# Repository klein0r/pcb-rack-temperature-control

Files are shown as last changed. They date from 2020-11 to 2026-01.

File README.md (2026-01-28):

# Rack Temperature Control

[Gerber-Files](https://github.com/klein0r/pcb-rack-temperature-control/releases)

## Preview

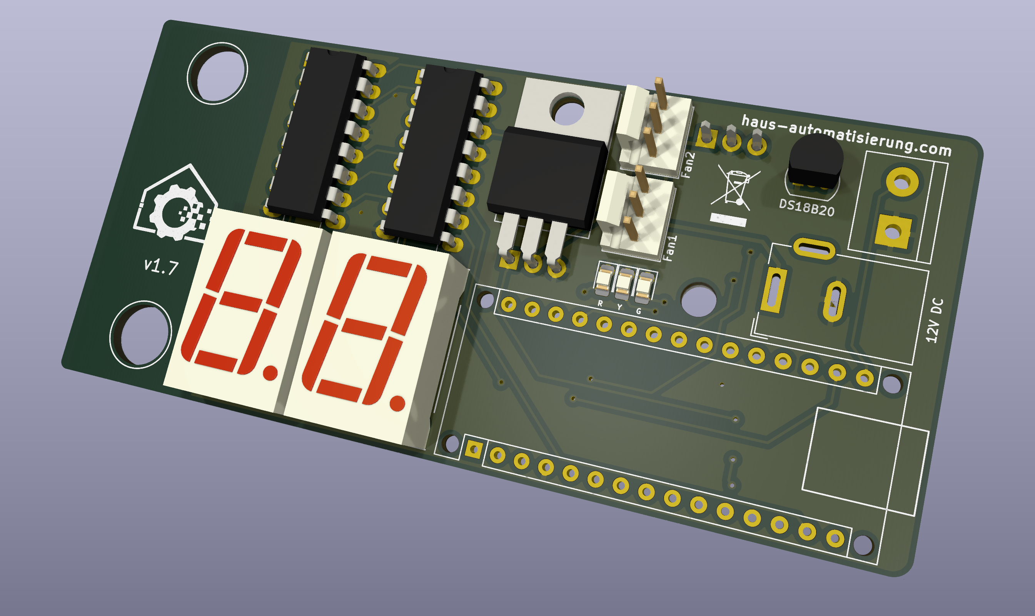
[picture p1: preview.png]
PCB Preview


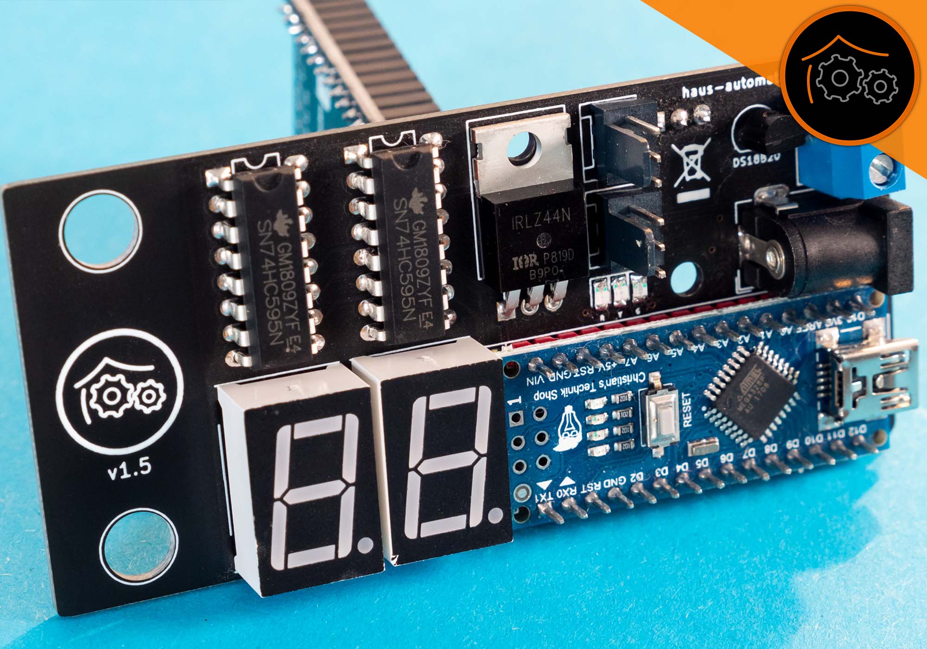
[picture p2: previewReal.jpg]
PCB Photo


## License

The MIT License (MIT)

Copyright (c) 2026 Matthias Kleine <info@haus-automatisierung.com>

Permission is hereby granted, free of charge, to any person obtaining a copy
of this software and associated documentation files (the "Software"), to deal
in the Software without restriction, including without limitation the rights
to use, copy, modify, merge, publish, distribute, sublicense, and/or sell
copies of the Software, and to permit persons to whom the Software is
furnished to do so, subject to the following conditions:

The above copyright notice and this permission notice shall be included in
all copies or substantial portions of the Software.

THE SOFTWARE IS PROVIDED "AS IS", WITHOUT WARRANTY OF ANY KIND, EXPRESS OR
IMPLIED, INCLUDING BUT NOT LIMITED TO THE WARRANTIES OF MERCHANTABILITY,
FITNESS FOR A PARTICULAR PURPOSE AND NONINFRINGEMENT. IN NO EVENT SHALL THE
AUTHORS OR COPYRIGHT HOLDERS BE LIABLE FOR ANY CLAIM, DAMAGES OR OTHER
LIABILITY, WHETHER IN AN ACTION OF CONTRACT, TORT OR OTHERWISE, ARISING FROM,
OUT OF OR IN CONNECTION WITH THE SOFTWARE OR THE USE OR OTHER DEALINGS IN
THE SOFTWARE.

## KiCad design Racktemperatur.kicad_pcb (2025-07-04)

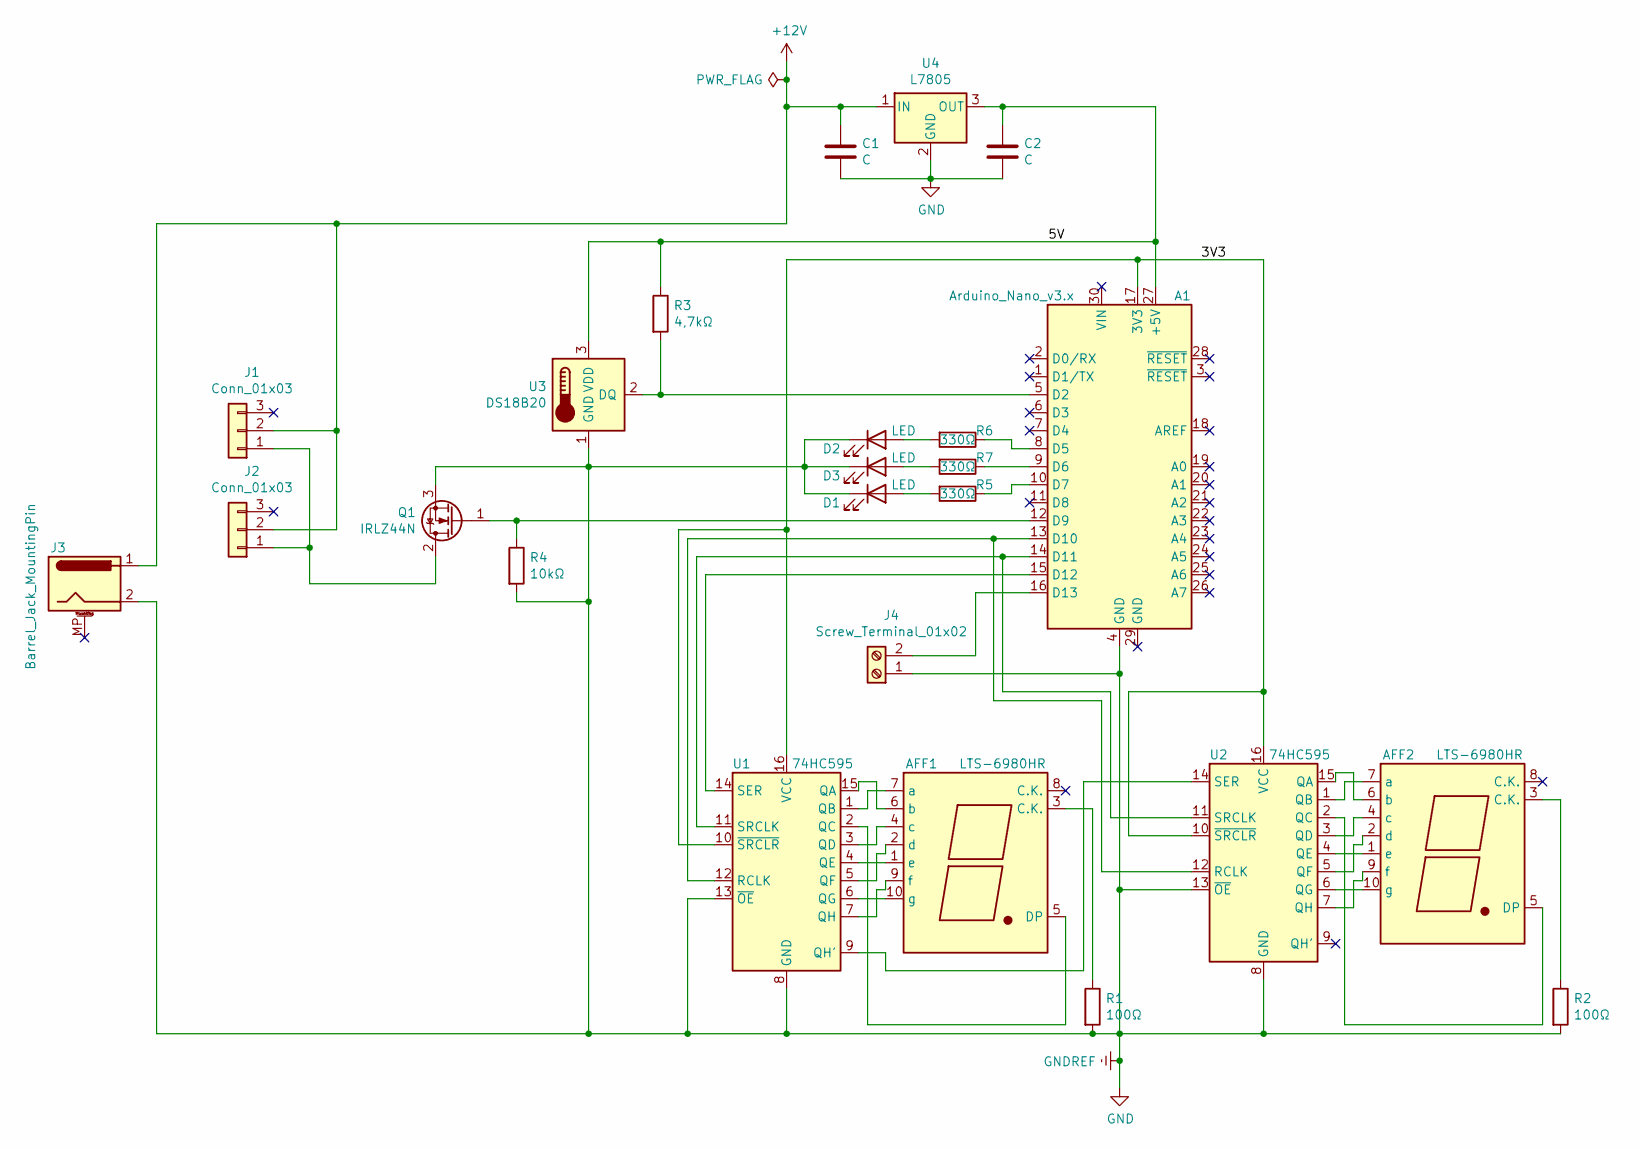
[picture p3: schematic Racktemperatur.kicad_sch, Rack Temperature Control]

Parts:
A1: Arduino_Nano_v3.x; Arduino_Nano_WithMountingHoles
AFF1, AFF2: LTS-6980HR; 7SegmentLED_LTS6760_LTS6780
C1, C2: C; C_0805_2012Metric_Pad1.18x1.45mm_HandSolder
D1, D2, D3: LED; LED_0805_2012Metric_Pad1.15x1.40mm_HandSolder
J1, J2: Conn_01x03; FanPinHeader_1x03_P2.54mm_Vertical
J3: Barrel_Jack_MountingPin; BarrelJack_Wuerth_6941xx301002
J4: Screw_Terminal_01x02; TerminalBlock_bornier-2_P5.08mm
Q1: IRLZ44N; TO-220-3_Horizontal_TabDown
R1, R2: 100Ω; R_0805_2012Metric_Pad1.20x1.40mm_HandSolder
R3: 4,7kΩ; R_0805_2012Metric_Pad1.20x1.40mm_HandSolder
R4: 10kΩ; R_0805_2012Metric_Pad1.20x1.40mm_HandSolder
R5, R6, R7: 330Ω; R_0805_2012Metric_Pad1.20x1.40mm_HandSolder
U1, U2: 74HC595; DIP-16_W7.62mm_LongPads
U3: DS18B20; TO-92_Inline
U4: L7805; TO-220-3_Horizontal_TabDown

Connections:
+12V: C1.1, J1.2, J2.2, J3.1, U4.1 (IN)
/3V3: A1.17 (3V3), U1.10 (~SRCLR), U1.16 (VCC), U2.10 (~SRCLR), U2.16 (VCC)
/5V: A1.27 (+5V), C2.1, R3.1, U3.3 (VDD), U4.3 (OUT)
GND: A1.4 (GND), C1.2, C2.2, D1.1 (K), D2.1 (K), D3.1 (K), J3.2, J4.1, Q1.3 (S), R1.2, R2.2, R4.2, U1.8 (GND), U1.13 (~OE), U2.8 (GND), U2.13 (~OE), U3.1 (GND), U4.2 (GND)
unnamed: A1.5 (D2), R3.2, U3.2 (DQ)
unnamed: A1.8 (D5), R6.1
unnamed: A1.9 (D6), R7.1
unnamed: A1.10 (D7), R5.1
unnamed: A1.12 (D9), Q1.1 (G), R4.1
unnamed: A1.13 (D10), U1.12 (RCLK), U2.12 (RCLK)
unnamed: A1.14 (D11), U1.11 (SRCLK), U2.11 (SRCLK)
unnamed: A1.15 (D12), U1.14 (SER)
unnamed: A1.16 (D13), J4.2
unnamed: AFF1.3 (C.K.), R1.1
unnamed: AFF1.5 (DP), U1.2 (QC)
unnamed: AFF1.7 (a), U1.1 (QB)
unnamed: AFF1.6 (b), U1.15 (QA)
unnamed: AFF1.4 (c), U1.3 (QD)
unnamed: AFF1.2 (d), U1.5 (QF)
unnamed: AFF1.1 (e), U1.4 (QE)
unnamed: AFF1.9 (f), U1.7 (QH)
unnamed: AFF1.10 (g), U1.6 (QG)
unnamed: AFF2.3 (C.K.), R2.1
unnamed: AFF2.5 (DP), U2.2 (QC)
unnamed: AFF2.7 (a), U2.1 (QB)
unnamed: AFF2.6 (b), U2.15 (QA)
unnamed: AFF2.4 (c), U2.3 (QD)
unnamed: AFF2.2 (d), U2.5 (QF)
unnamed: AFF2.1 (e), U2.4 (QE)
unnamed: AFF2.9 (f), U2.7 (QH)
unnamed: AFF2.10 (g), U2.6 (QG)
unnamed: D1.2 (A), R5.2
unnamed: D2.2 (A), R6.2
unnamed: D3.2 (A), R7.2
unnamed: J1.1, J2.1, Q1.2 (D)
unnamed: U1.9 (QH'), U2.14 (SER)

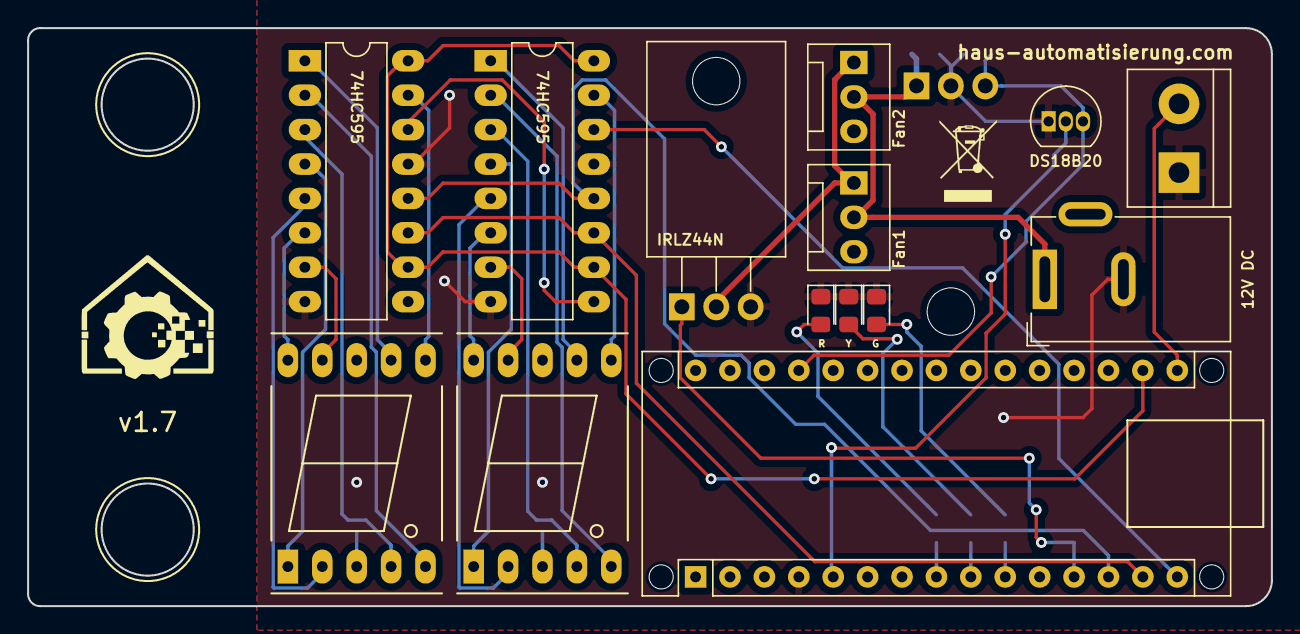
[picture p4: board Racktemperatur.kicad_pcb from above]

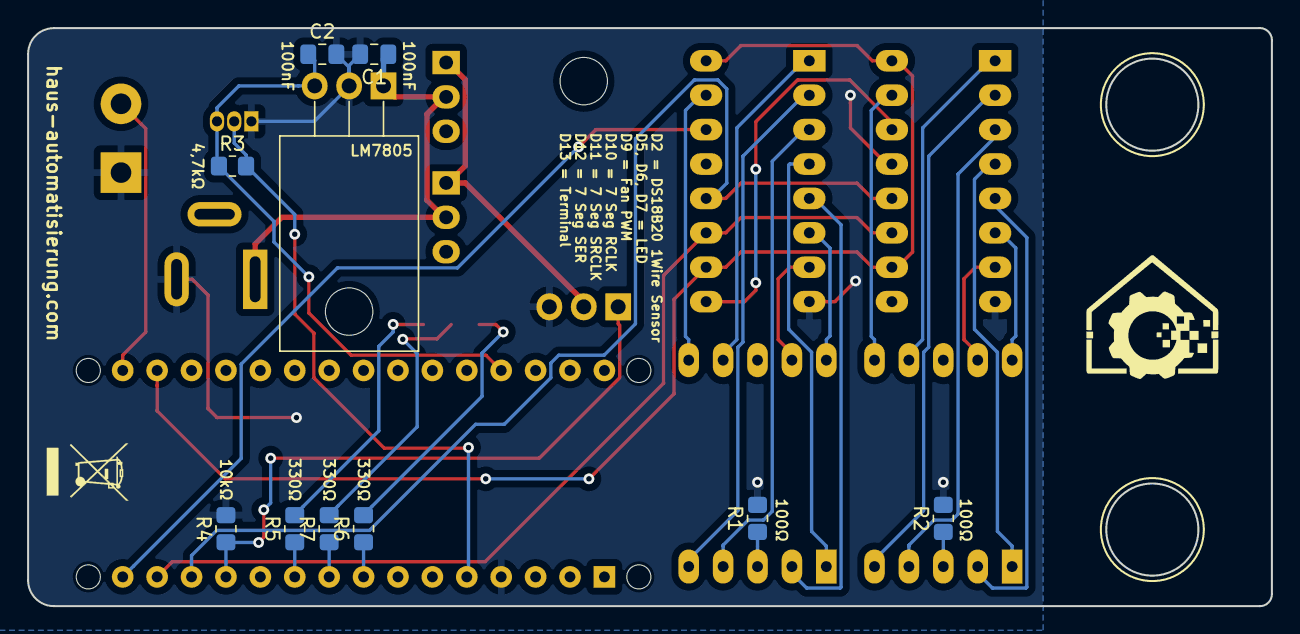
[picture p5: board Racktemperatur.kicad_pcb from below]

Board: 2 copper layers, 91.8 x 42.7 mm, 24 parts (10 on the bottom side), 36 nets.

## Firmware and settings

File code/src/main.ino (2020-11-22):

#include <Arduino.h>
#include <OneWire.h>
#include <DallasTemperature.h>

#define LED_PIN_R 5
#define LED_PIN_Y 6
#define LED_PIN_G 7
#define FAN_PIN 9
#define REED_PIN 13

#define SHIFT_PIN 11 // SH_CP
#define STORE_PIN 10 // ST_CP
#define DATA_PIN 12  // DS

#define ONE_WIRE_BUS 2

OneWire oneWire(ONE_WIRE_BUS);
DallasTemperature sensors(&oneWire);

bool numbers[10][8] = {
  {HIGH, LOW, HIGH, HIGH, HIGH, LOW, HIGH, HIGH},
  {LOW, LOW, LOW, LOW, HIGH, LOW, LOW, HIGH},
  {LOW, HIGH, HIGH, HIGH, LOW, LOW, HIGH, HIGH},
  {LOW, HIGH, HIGH, LOW, HIGH, LOW, HIGH, HIGH},
  {HIGH, HIGH, LOW, LOW, HIGH, LOW, LOW, HIGH},
  {HIGH, HIGH, HIGH, LOW, HIGH, LOW, HIGH, LOW},
  {HIGH, HIGH, HIGH, HIGH, HIGH, LOW, HIGH, LOW},
  {LOW, LOW, LOW, LOW, HIGH, LOW, HIGH, HIGH},
  {HIGH, HIGH, HIGH, HIGH, HIGH, LOW, HIGH, HIGH},
  {HIGH, HIGH, HIGH, LOW, HIGH, LOW, HIGH, HIGH},
};

int n = 0;
int temperature = 0;

void writeDigit(int digit) {
  if (digit >= 0 && digit <= 9) {
    for (int i = 0; i < 8; i++) {
      digitalWrite(SHIFT_PIN, LOW);
      digitalWrite(DATA_PIN, numbers[digit][i]);
      digitalWrite(SHIFT_PIN, HIGH);
    }
  }
}

void blackDisplay()
{
  digitalWrite(STORE_PIN, LOW);
  for (int i = 0; i < 16; i++) {
    digitalWrite(SHIFT_PIN, LOW);
    digitalWrite(DATA_PIN, LOW);
    digitalWrite(SHIFT_PIN, HIGH);
  }
  digitalWrite(STORE_PIN, HIGH);
}

void writeNumber(int number) {
  if (number >= 0 && number < 100) {
    digitalWrite(STORE_PIN, LOW);
    if (number < 10) {
      writeDigit(0);
      writeDigit(number);
    } else {
      writeDigit(floor(number / 10));
      writeDigit(number % 10);
    }
    digitalWrite(STORE_PIN, HIGH);
  }
}

void setup() {
  Serial.begin(9600);
  TCCR1B = TCCR1B & 0b11111000 | 0x01;

  sensors.begin();

  pinMode(LED_PIN_G, OUTPUT);
  pinMode(LED_PIN_Y, OUTPUT);
  pinMode(LED_PIN_R, OUTPUT);
  pinMode(LED_BUILTIN, OUTPUT);

  pinMode(FAN_PIN, OUTPUT);
  pinMode(REED_PIN, INPUT_PULLUP);

  pinMode(SHIFT_PIN, OUTPUT);
  pinMode(STORE_PIN, OUTPUT);
  pinMode(DATA_PIN, OUTPUT);
  blackDisplay();

  digitalWrite(STORE_PIN, LOW);

  writeNumber(99);
}

void loop() {
  digitalWrite(LED_BUILTIN, HIGH);
  delay(100);
  digitalWrite(LED_BUILTIN, LOW);
  delay(100);

  sensors.requestTemperatures();
  temperature = floor(sensors.getTempCByIndex(0));

  writeNumber(temperature);

  if (temperature < 25) {
    analogWrite(FAN_PIN, 0);
    digitalWrite(LED_PIN_R, LOW);
    digitalWrite(LED_PIN_Y, LOW);
    digitalWrite(LED_PIN_G, HIGH);
  } else if (temperature > 30) {
    analogWrite(FAN_PIN, 255);
    digitalWrite(LED_PIN_R, HIGH);
    digitalWrite(LED_PIN_Y, LOW);
    digitalWrite(LED_PIN_G, LOW);
  } else {
    analogWrite(FAN_PIN, 128);
    digitalWrite(LED_PIN_R, LOW);
    digitalWrite(LED_PIN_Y, HIGH);
    digitalWrite(LED_PIN_G, LOW);
  }

  delay(1000);
}

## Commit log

2019-10-25 Version 1.3 as rack mount
    [Racktemperatur.kicad_pcb, Racktemperatur.sch]
2019-10-26 unconnected item
    [Racktemperatur.kicad_pcb, Racktemperatur.sch]
2019-10-26 Added LM7805
    [Racktemperatur.kicad_pcb, Racktemperatur.sch]
2019-11-12 Changed polarity of barrel jack
    [Racktemperatur.kicad_pcb, Racktemperatur.sch]
2019-11-12 Schema update
    [Racktemperatur.sch]
2019-11-12 Minor changes
    [Racktemperatur.kicad_pcb, Racktemperatur.sch]
2020-11-22 Added Source Code
    [Racktemperatur.kicad_pcb]
2022-01-31 Updated to KiCad 6
    [Racktemperatur.kicad_pcb, Racktemperatur.kicad_sch, Racktemperatur.sch]
2025-07-04 Updated PCB
    [Racktemperatur.kicad_pcb, Racktemperatur.kicad_sch]
